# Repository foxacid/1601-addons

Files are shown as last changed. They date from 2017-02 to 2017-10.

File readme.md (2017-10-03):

# 1601 Clone Add-Ons

This repository contains a front panel design and divider add-on (circuit design by [Matthias Herrmann aka Fonik](http://www.modular.fonik.de/)) for the [1601 clone project by Kipling](https://www.muffwiggler.com/forum/viewtopic.php?t=110640).

## One Thousand Six Hundred and One Panel 

Just like the [TTSH](http://www.thehumancomparator.net/) panel, this 1601 front panel design is inspired by the ARP 2600 'Grey Meanie' layout and colour scheme. To match the TTSH, the text is set in 9pt Helvetica (white on RAL 7016 Anthrazitgrau).

The layout fits Kiplings 1601 clone PCBS Rev 1-3. Additionally there is a provision for 6 extra jacks above the power switch to the right to accomodate the Clock Divider add-on.

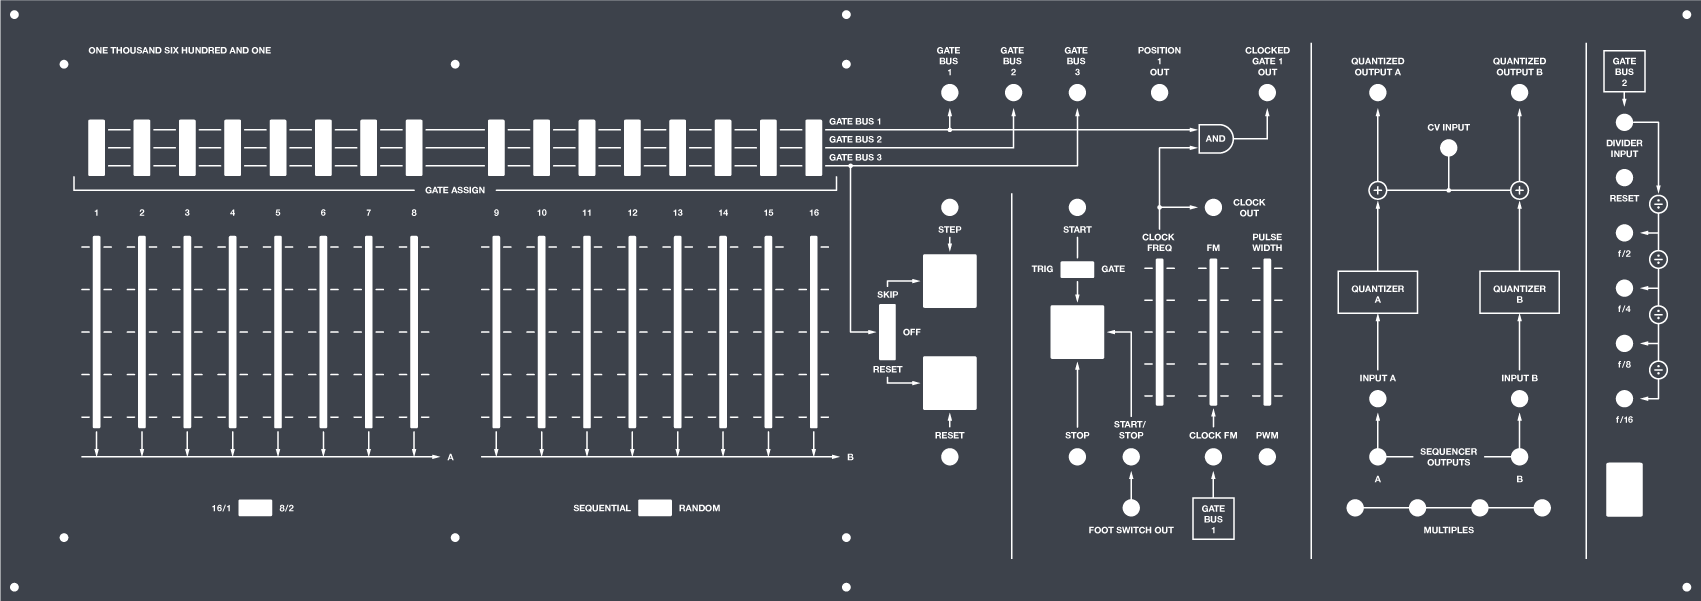
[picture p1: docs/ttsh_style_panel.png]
Panel


## Divider PCB

The Clock Divider is based on an [original design by Matthias Herrmann](http://www.modular.fonik.de/pdf/SimpleDividerSCH.pdf) - thanks Matthias! The clock-divider folder contains the EAGLE source files and Gerbers generated with [Seeed Studio](https://www.seeedstudio.com/) design rules. A unipolar +15V power source is required.

There is a provision for normalising Gate Output 2 to the divider's clock input. There are also provisions for LED indicators and a manual Reset button. Those are not present on the front panel.

### PCB

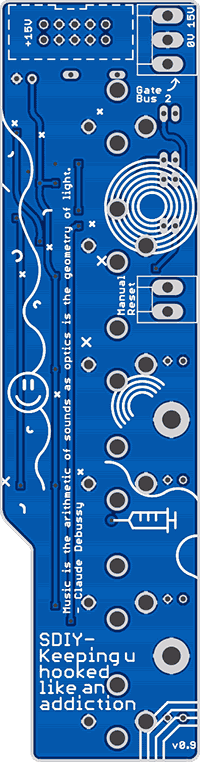
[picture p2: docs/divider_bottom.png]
PCB bottom
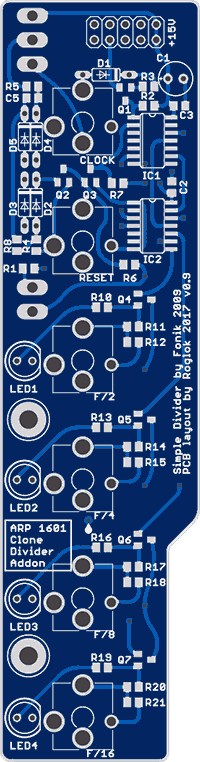
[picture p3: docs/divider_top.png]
PCB top
 

### Bill of Materials

 - - - -
**Make sure to use 15V versions for the logic ICs**
 - - - -

Name                 |  Value       |  Package 
-----------------    | ------------ | ------------
***Capacitors***     |              |         
C1                   |  100uF       |  Radial, 2.5mm spacing
C2                   |  0.1µF       |  0805
C3                   |  0.1µF       |  0805
C5                   |  0.01µF      |  0805
***Semiconductors*** |              |         
D1-D4                |  1N4148      |  DO35 
Q1-Q7                |  BC850       |  SOT23
IC1                  |  4024D       |  SO14
IC2                  |  4069D       |  SO14
***Resistors***      |              |      
R1                   |  47K         |  0805
R2                   |  10K         |  0805
R3                   |  47K         |  0805
R4                   |  100K        |  0805
R5                   |  100K        |  0805
R6                   |  10K         |  0805
R7                   |  10K         |  0805
R8                   |  47K         |  0805
R10                  |  2K2         |  0805
R11                  |  1K          |  0805
R12                  |  2K2         |  0805
R13                  |  2K2         |  0805
R14                  |  1K          |  0805
R15                  |  2K2         |  0805
R16                  |  2K2         |  0805
R17                  |  1K          |  0805
R18                  |  2K2         |  0805
R19                  |  2K2         |  0805
R20                  |  1K          |  0805
R21                  |  2K2         |  0805
***Jacks***          |              |    
CLOCK                |  PJ301BM     |  3,5mm Mono
RESET                |  PJ301BM     |  3,5mm Mono
F/2                  |  PJ301BM     |  3,5mm Mono
F/4                  |  PJ301BM     |  3,5mm Mono
F/8                  |  PJ301BM     |  3,5mm Mono
F/16                 |  PJ301BM     |  3,5mm Mono

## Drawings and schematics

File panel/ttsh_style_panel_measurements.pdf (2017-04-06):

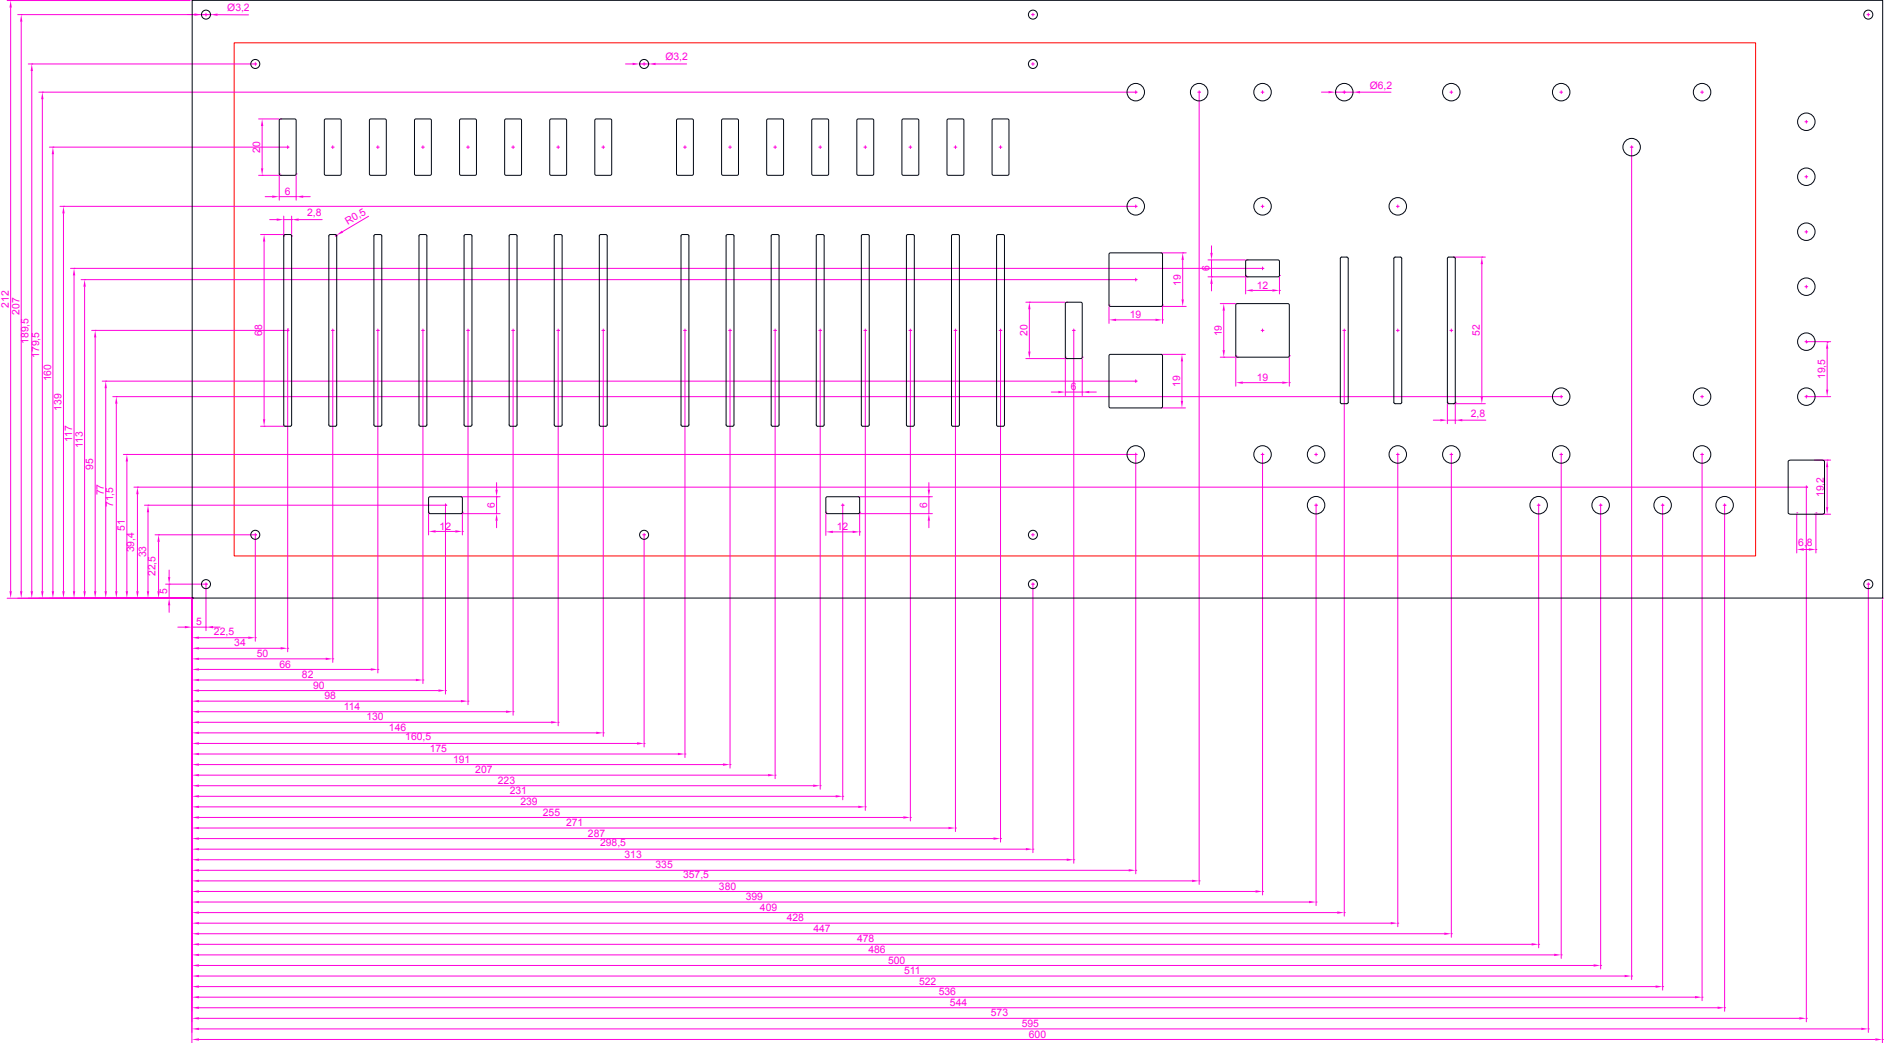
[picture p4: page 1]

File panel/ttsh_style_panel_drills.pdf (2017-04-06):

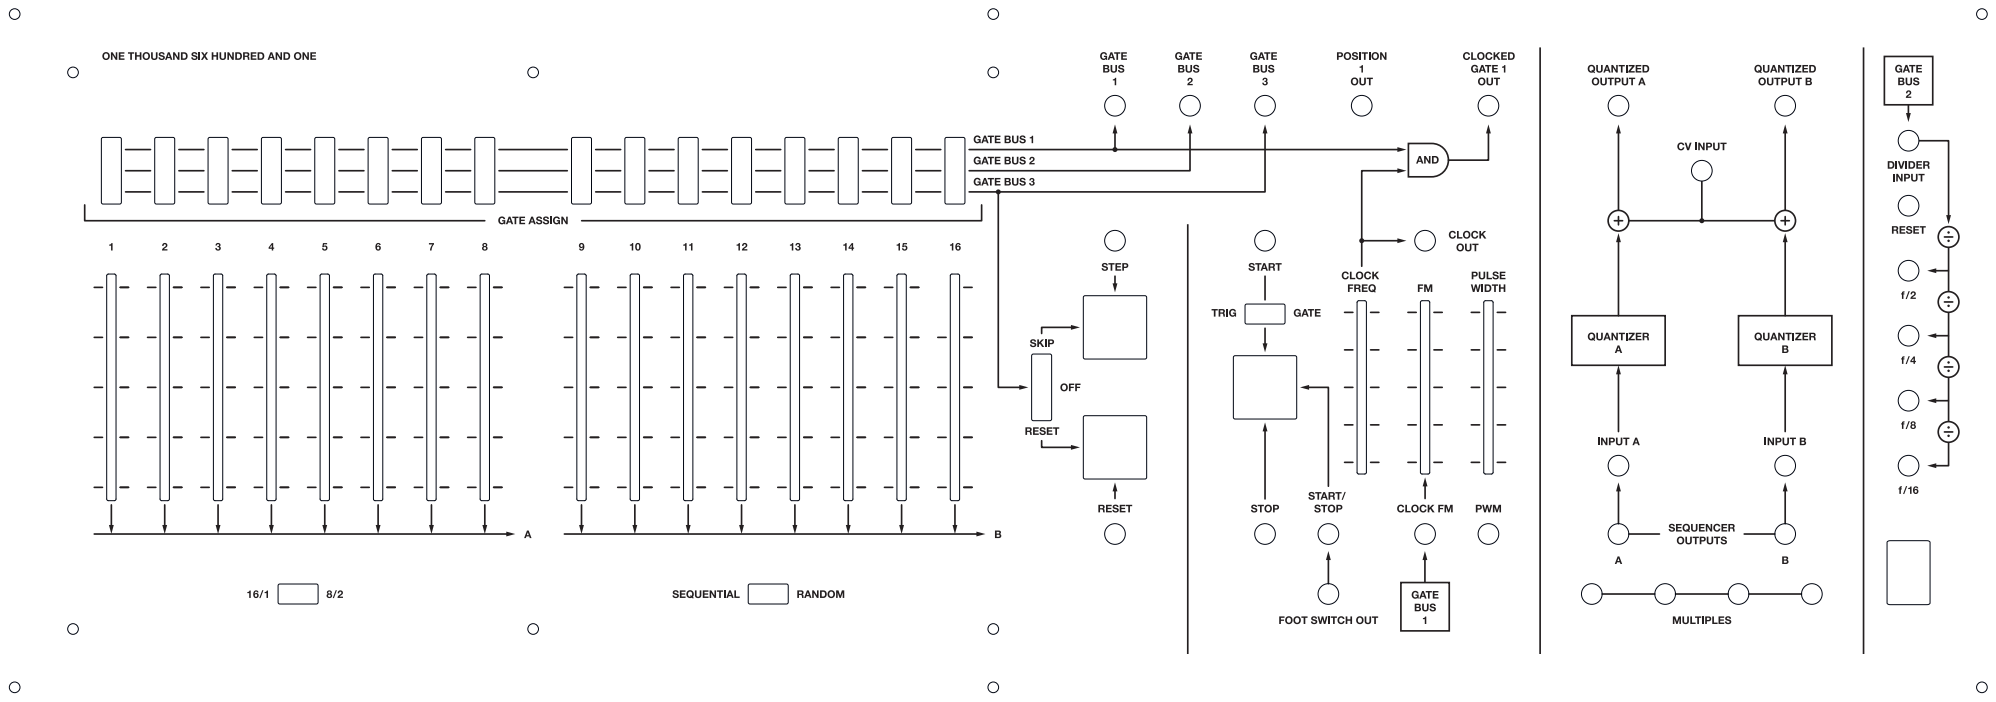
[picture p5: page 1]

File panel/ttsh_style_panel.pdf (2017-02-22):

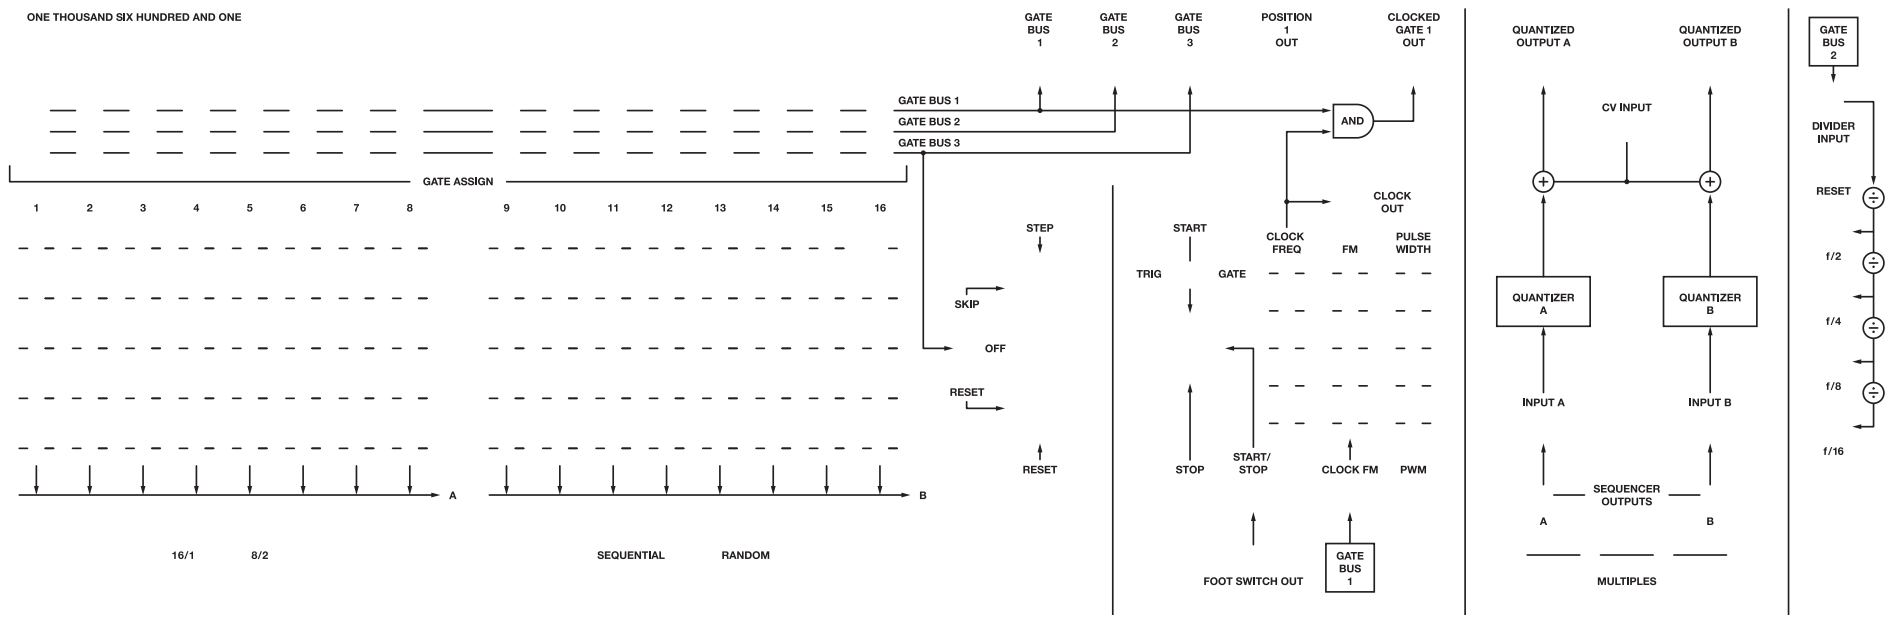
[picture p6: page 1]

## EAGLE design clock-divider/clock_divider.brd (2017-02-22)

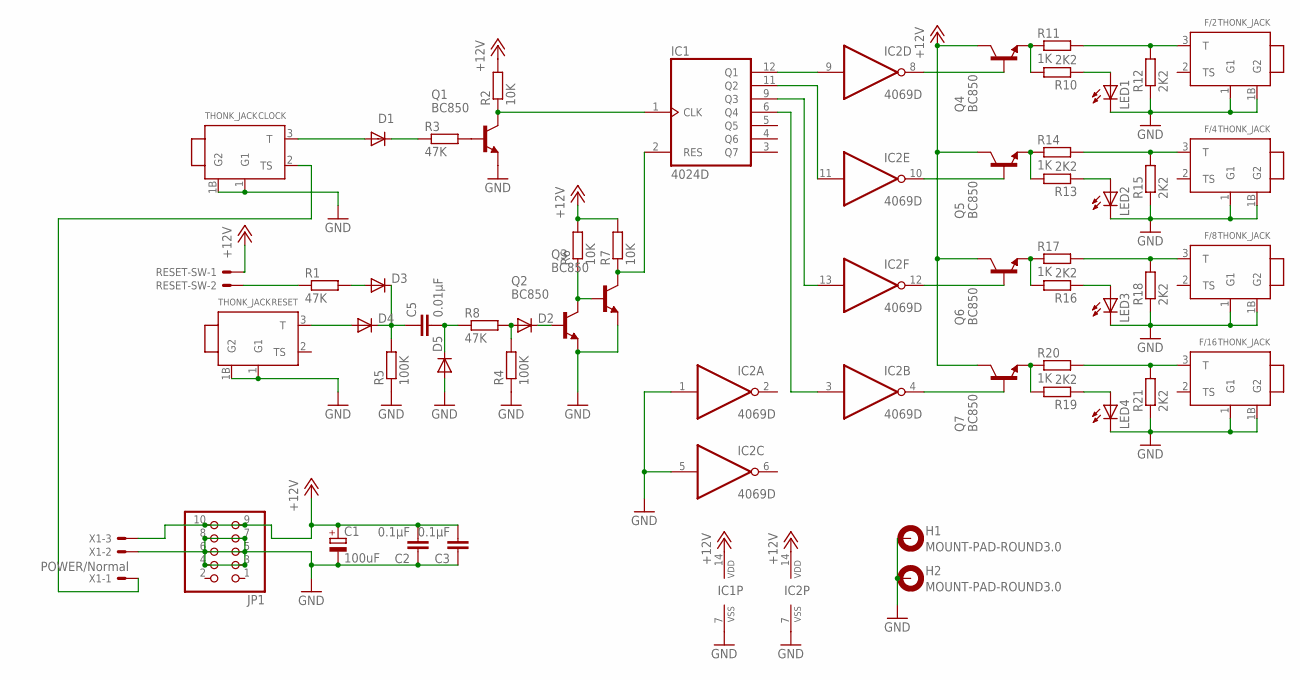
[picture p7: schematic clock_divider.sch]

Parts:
C1: 100uF; E2,5-6E
C2, C3: 0.1µF; C0805
C5: 0.01µF; C0805
CLOCK: THONK_JACK; THONK_JACK_P
D1, D2, D3, D4, D5: 1N4148; DO35-7
F/2, F/4, F/8, F/16: THONK_JACK; THONK_JACK_P
H1, H2: MOUNT-PAD-ROUND3.0; 3,0-PAD
IC1: 4024D; SO14
IC2: 4069D; SO14
JP1: PINHD-2X5; 2X05
LED1, LED2, LED3, LED4: LED5MM
Q1, Q2, Q3, Q4, Q5, Q6, Q7: BC850; SOT23
R1, R3, R8: 47K; M0805
R2, R6, R7: 10K; M0805
R4, R5: 100K; M0805
R10, R12, R13, R15, R16, R18, R19, R21: 2K2; M0805
R11, R14, R17, R20: 1K; M0805
RESET: THONK_JACK; THONK_JACK_P
RESET-SW: KK-156-2
X1: POWER/Normal; KK-156-3

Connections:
+12V: C1.+, C2.2, C3.2, IC1.14 (VDD), IC2.14 (VDD), JP1.9, JP1.10, Q4.3 (C), Q5.3 (C), Q6.3 (C), Q7.3 (C), R2.2, R6.2, R7.2, RESET-SW.1, X1.3
GND: C1.-, C2.1, C3.1, CLOCK.1 (G1), CLOCK.1B (G2), D5.A, F/2.1 (G1), F/2.1B (G2), F/4.1 (G1), F/4.1B (G2), F/8.1 (G1), F/8.1B (G2), F/16.1 (G1), F/16.1B (G2), H1.B3,0, H2.B3,0, IC1.7 (VSS), IC2.1 (I), IC2.5 (I), IC2.7 (VSS), JP1.3, JP1.4, JP1.5, JP1.6, JP1.7, JP1.8, LED1.K (C), LED2.K (C), LED3.K (C), LED4.K (C), Q1.2 (E), Q2.2 (E), Q3.2 (E), R4.1, R5.1, R12.1, R15.1, R18.1, R21.1, RESET.1 (G1), RESET.1B (G2), X1.2
unnamed: Q4.2 (E), R10.2, R11.1
unnamed: IC1.12 (Q1), IC2.9 (I)
unnamed: IC1.11 (Q2), IC2.11 (I)
unnamed: Q1.1 (B), R3.2
unnamed: IC1.1 (CLK), Q1.3 (C), R2.1
unnamed: D1.C, R3.1
unnamed: CLOCK.3 (T), D1.A
unnamed: D4.A, RESET.3 (T)
unnamed: C5.1, D3.C, D4.C, R5.2
unnamed: C5.2, D5.C, R8.1
unnamed: D2.A, R4.2, R8.2
unnamed: D2.C, Q2.1 (B)
unnamed: Q2.3 (C), Q3.1 (B), R6.1
unnamed: IC1.2 (RES), Q3.3 (C), R7.1
unnamed: IC1.9 (Q3), IC2.13 (I)
unnamed: IC1.6 (Q4), IC2.3 (I)
unnamed: LED2.A, R13.1
unnamed: IC2.8 (O), Q4.1 (B)
unnamed: LED4.A, R19.1
unnamed: F/4.3 (T), R14.2, R15.2
unnamed: Q5.2 (E), R13.2, R14.1
unnamed: IC2.10 (O), Q5.1 (B)
unnamed: F/8.3 (T), R17.2, R18.2
unnamed: Q6.2 (E), R16.2, R17.1
unnamed: IC2.12 (O), Q6.1 (B)
unnamed: F/16.3 (T), R20.2, R21.2
unnamed: Q7.2 (E), R19.2, R20.1
unnamed: IC2.4 (O), Q7.1 (B)
unnamed: LED3.A, R16.1
unnamed: LED1.A, R10.1
unnamed: D3.A, R1.2
unnamed: R1.1, RESET-SW.2
unnamed: CLOCK.2 (TS), X1.1
unnamed: F/2.3 (T), R11.2, R12.2

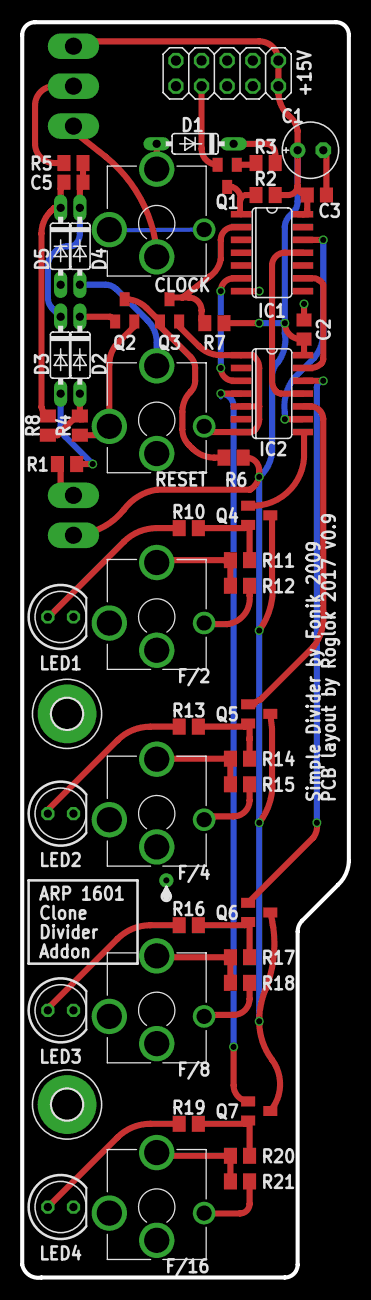
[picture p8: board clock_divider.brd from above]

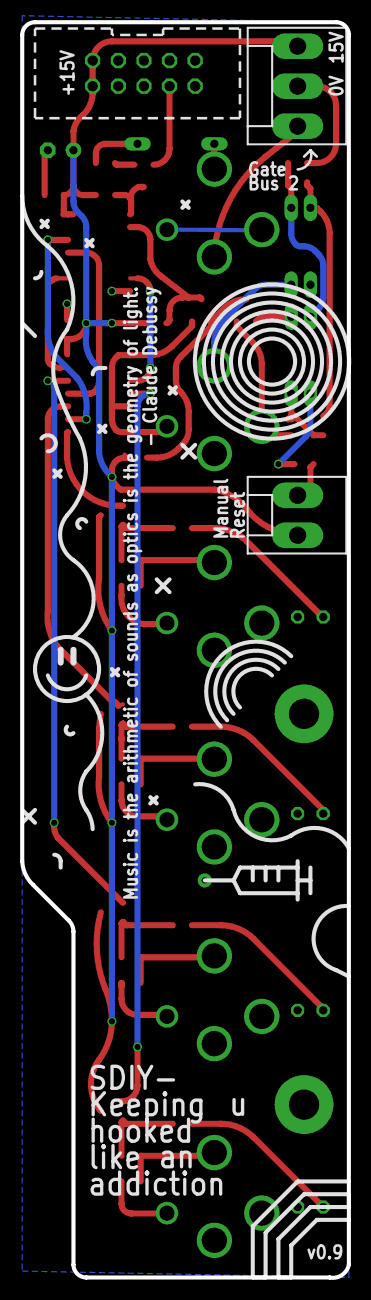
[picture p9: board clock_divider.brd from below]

Board: 2 copper layers, 32.4 x 124.5 mm, 53 parts (2 on the bottom side), 36 nets.

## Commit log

2017-02-23 Resize PCB images
2017-02-23 Add BOM
2017-04-06 Add measurement and drilling patterns
2017-10-03 Add note to use high voltage version for 4024
